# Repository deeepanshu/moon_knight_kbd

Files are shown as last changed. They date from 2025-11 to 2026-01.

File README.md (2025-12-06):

# Moon Knight Keyboard

A custom split keyboard project with multiple hardware iterations and utilities.

## Project Structure

- **moon_knight_v1/** - Initial keyboard design
- **moon_knight_v2_left/** & **moon_knight_v2_right/** - Second iteration split keyboard
- **moon_knight_v3/** - Third iteration
- **moon_knight_v4/** - Latest iteration
- **firmwares/** - Keyboard firmware configurations
- **keeb_utils/** - Utility tools for the keyboard
  - **layer-display/** - Real-time layer visualization utility

## Resources

- [Switch Placement Grid Guide](https://discord.com/channels/1025609366180728904/1096999853084655717/1358123429684838441) - Discord discussion on proper switch placement in grid layout

## Hardware Files

- `moon_knight_v2_case_design.stl` - Case design for v2
- `moon_knight_v2_switch_plates.stl` - Switch plates for v2

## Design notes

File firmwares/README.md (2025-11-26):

I am creating this folder to keep track of firmwares I used in QMK.
This folders contents should be symlinks in qmk_firmware/keyboards folder.

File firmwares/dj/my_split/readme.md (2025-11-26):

# dj/my_split

dj/my_split

*A short description of the keyboard/project*

* Keyboard Maintainer: [Deepanshu Jain](https://github.com/deeepanshu)
* Hardware Supported: *The PCBs, controllers supported*
* Hardware Availability: *Links to where you can find this hardware*

Make example for this keyboard (after setting up your build environment):

    make dj/my_split:default

Flashing example for this keyboard:

    make dj/my_split:default:flash

See the [build environment setup](https://docs.qmk.fm/#/getting_started_build_tools) and the [make instructions](https://docs.qmk.fm/#/getting_started_make_guide) for more information. Brand new to QMK? Start with our [Complete Newbs Guide](https://docs.qmk.fm/#/newbs).

## Bootloader

Enter the bootloader in 3 ways:

* **Bootmagic reset**: Hold down the key at (0,0) in the matrix (usually the top left key or Escape) and plug in the keyboard
* **Physical reset button**: Briefly press the button on the back of the PCB - some may have pads you must short instead
* **Keycode in layout**: Press the key mapped to `QK_BOOT` if it is available

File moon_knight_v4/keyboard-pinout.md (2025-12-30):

## Moon Knight V4 Keyboard Pinout (Per Side)

### Matrix (4 rows × 6 columns)
**Rows:**
- Row 0: GPIO 4
- Row 1: GPIO 5
- Row 2: GPIO 6
- Row 3: GPIO 7

**Columns:**
- Col 0: GPIO 8
- Col 1: GPIO 9
- Col 2: GPIO 20
- Col 3: GPIO 21
- Col 4: GPIO 22
- Col 5: GPIO 23

### LEDs (27 addressable per side)
- LED Data: GPIO 25 (5V RGB output)

### TRRS Split Communication
- TX: GPIO 0 (UART transmit)
- RX: GPIO 1 (UART receive)

### OLED Display
- SDA: GPIO 2 (I2C data)
- SCL: GPIO 3 (I2C clock)

### Pin Summary
Total pins used: 15
- Matrix: 10 pins (4 rows + 6 cols)
- RGB LEDs: 1 pin
- TRRS: 2 pins
- OLED: 2 pins

### Unusable Pins
- **D+, D-** - USB data (required)
- **RAW, GND, 3V3, nRST** - Power/reset lines
- **GPIO 12-16** - Bottom pads (avoiding per requirements)

### Available GPIO Pins
Total available: 18 pins (0-11, 20-23, 26-29)
Used: 15 pins
Remaining: GPIO 10, 11, 26 (3 pins free for expansion)

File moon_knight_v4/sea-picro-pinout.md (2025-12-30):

## Sea-Picro EXT Pinout

### Left Side
- **D+** - USB Data Positive
- **0** - TX (UART)
- **1** - RX (UART)
- **GND** - Ground
- **GND** - Ground
- **2** - SDA (I2C)
- **3** - SCL (I2C)
- **4** - GPIO
- **5** - GPIO
- **6** - GPIO
- **7** - GPIO
- **8** - GPIO
- **9** - GPIO

### Right Side
- **D-** - USB Data Negative
- **RAW** - Raw power input
- **GND** - Ground
- **nRST** - Reset (active low)
- **3V3** - 3.3V output
- **29** - ADC3
- **28** - ADC2
- **27** - ADC1
- **26** - ADC0
- **22** - SCK (SPI)
- **20** - MISO (SPI)
- **23** - MOSI (SPI)
- **21** - nCS (SPI)

### Bottom Pads
- **12, 13, 14, 15, 16** - Extended GPIO
- **25** - 5V RGB output

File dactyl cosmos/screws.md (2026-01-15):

# Dactly Cosmos

### Screws and Heat inserts notes

You'll need 14 M3 x 6mm screws with countersunk heads and 14 screw inserts to fasten the base plate to the case. Check the Screws Documentation to make sure you have the correctly sized parts.
https://ryanis.cool/cosmos/docs/screws/

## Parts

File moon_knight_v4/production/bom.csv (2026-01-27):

Designator | Footprint | Quantity | Value | LCSC Part #
C1, C10, C11, C12, C13, C14, C15, C16, C17, C18, C19, C2, C20, C21, C3, C4, C5, C6, C7, C8, C9 | 1206 | 21 | 0.1µF
CH1, CH10, CH11, CH12, CH13, CH14, CH15, CH16, CH17, CH18, CH19, CH2, CH20, CH3, CH4, CH5, CH6, CH7, CH8, CH9 | SW_choc_v1_HS_CPG135001S30_1u | 20 | choc_v1_SW_HS
CH21 | SW_choc_v1_HS_CPG135001S30_1.5u | 1 | choc_v1_SW_HS
D1, D10, D11, D12, D13, D14, D15, D16, D17, D18, D19, D2, D20, D21, D3, D4, D5, D6, D7, D8, D9 | D_SOD-123 | 21 | 1N4148W
J1 | CON_MJ-4PP-9 | 1 | AudioJack4
LED1, LED10, LED11, LED12, LED13, LED14, LED15, LED16, LED17, LED18, LED19, LED2, LED20, LED21, LED3, LED4, LED5, LED6, LED7, LED8, LED9 | LED_6028R | 21 | SK6812MINI-E
R1, R2 | 1206 | 2 | R
R3 | 1206 | 1 | 47R

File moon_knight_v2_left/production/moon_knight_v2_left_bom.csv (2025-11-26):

Designator | Footprint | Quantity | Value | LCSC Part #
C1, C10, C11, C12, C13, C14, C15, C16, C17, C18, C19, C2, C20, C21, C22, C3, C4, C5, C6, C7, C8, C9 | 1206 | 22 | 0.1µF
C23, C24, C25 | 1210 | 3 | 100uF
CH1, CH10, CH11, CH12, CH13, CH14, CH15, CH16, CH17, CH18, CH19, CH2, CH20, CH3, CH4, CH5, CH6, CH7, CH8, CH9 | SW_choc_v1_HS_CPG135001S30_1u | 20 | choc_v1_SW_HS
CH21, CH22 | SW_choc_v1_HS_CPG135001S30_1.5u | 2 | choc_v1_SW_HS
D1, D10, D11, D12, D13, D14, D15, D16, D17, D18, D19, D2, D20, D21, D22, D3, D4, D5, D6, D7, D8, D9 | D_SOD-123 | 22 | 1N4148W
J1 | CON_MJ-4PP-9_Reversible | 1 | AudioJack4
LED1, LED10, LED11, LED12, LED13, LED14, LED15, LED16, LED17, LED18, LED19, LED2, LED20, LED21, LED22, LED3, LED4, LED5, LED6, LED7, LED8, LED9 | LED_6028R | 22 | SK6812MINI-E
R1, R2 | 1206 | 2 | R
R3 | 1206 | 1 | 47R

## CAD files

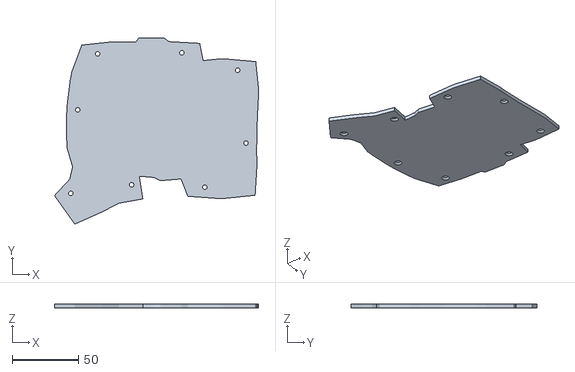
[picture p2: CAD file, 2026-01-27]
cosmotyl-6x4/cosmotyl-6x4-plateright.stl
154.1 x 140.6 x 3.00

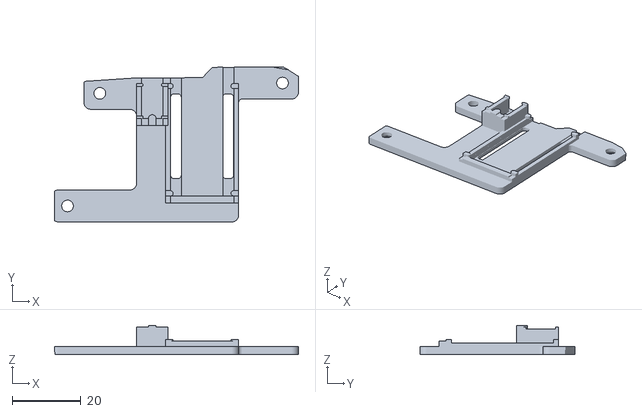
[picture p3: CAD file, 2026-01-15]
dactyl cosmos/cosmotyl-holderright.stl
71.0 x 45.1 x 8.50

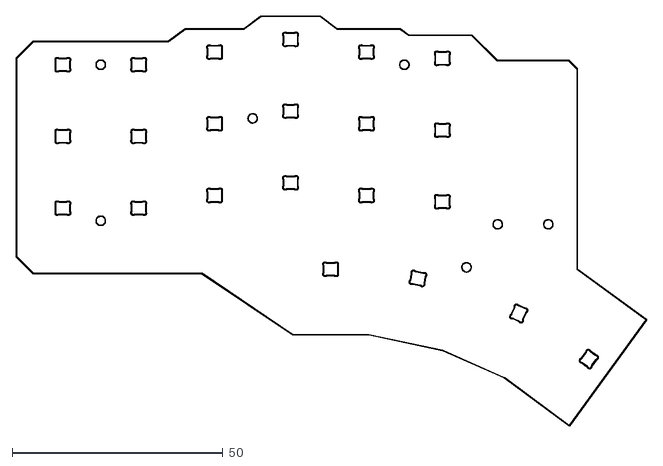
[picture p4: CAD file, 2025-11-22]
moon_knight_v2_left/dxfs/moon_knight_v2_left-Edge_Cuts.dxf
149.5 x 97.1

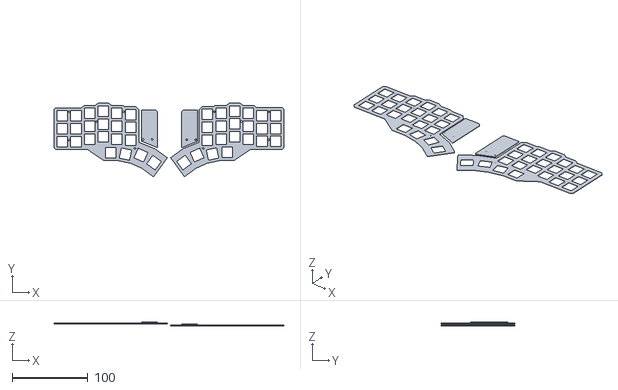
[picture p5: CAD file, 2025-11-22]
moon_knight_v2_switch_plates.stl
303.0 x 97.2 x 5.00

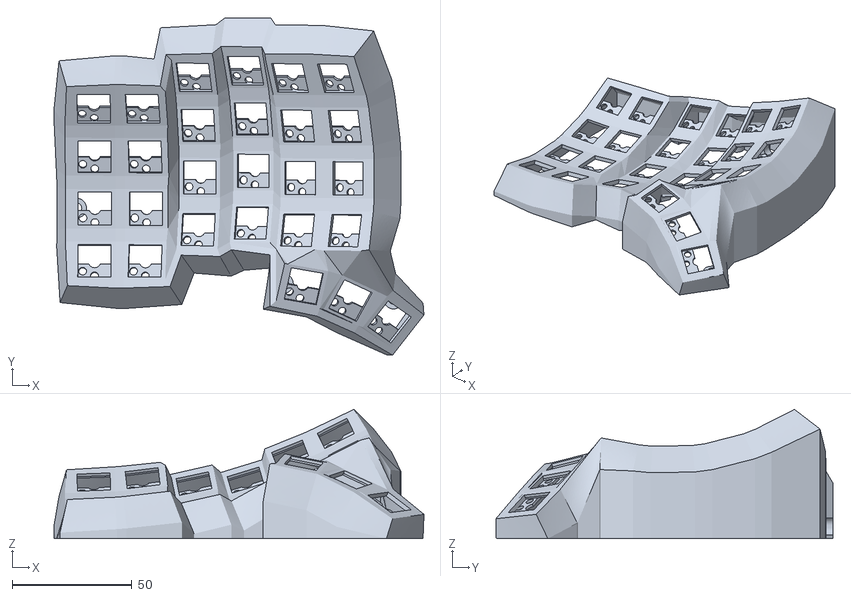
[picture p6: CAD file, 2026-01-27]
cosmotyl-6x4/cosmotyl-6x4-caseleft.stl
154.5 x 140.8 x 53.9

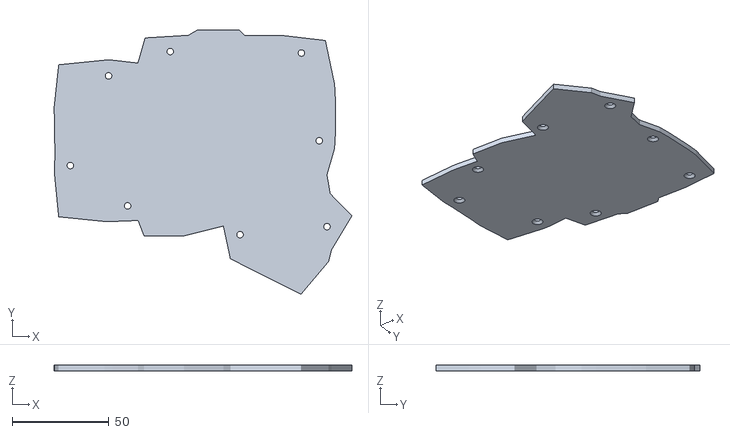
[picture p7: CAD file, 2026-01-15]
dactyl cosmos/cosmotyl-plateleft.stl
154.3 x 136.9 x 3.00

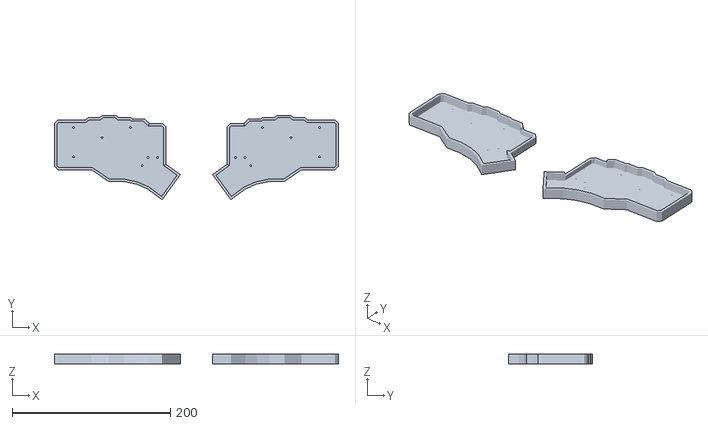
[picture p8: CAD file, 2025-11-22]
moon_knight_v2_case_design.stl
358.6 x 106.6 x 12.0

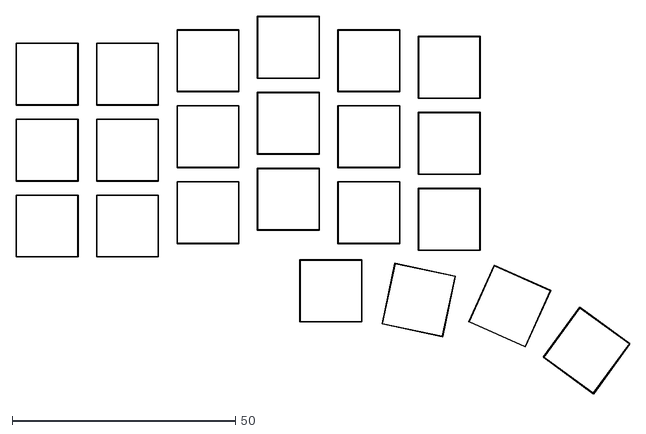
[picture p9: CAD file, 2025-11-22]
moon_knight_v2_left/dxfs/moon_knight_v2_left-F_Courtyard.dxf
137.3 x 84.4

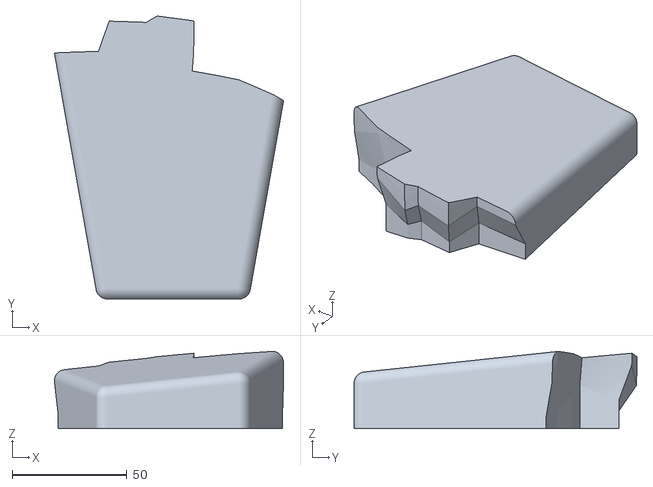
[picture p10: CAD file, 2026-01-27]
cosmotyl-6x4/cosmotyl-6x4-wristrestleft.stl
100.0 x 123.4 x 33.7

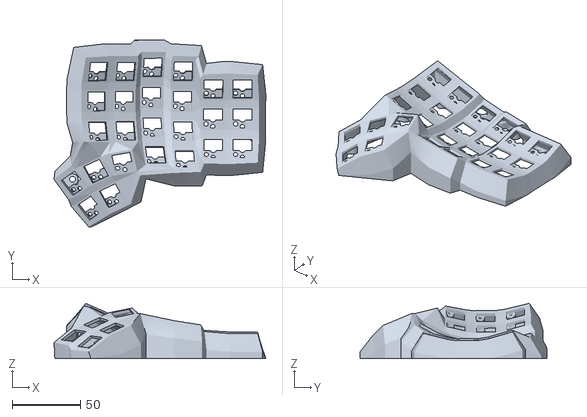
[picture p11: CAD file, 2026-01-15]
dactyl cosmos/cosmotyl-caseright.stl
154.9 x 136.9 x 40.4

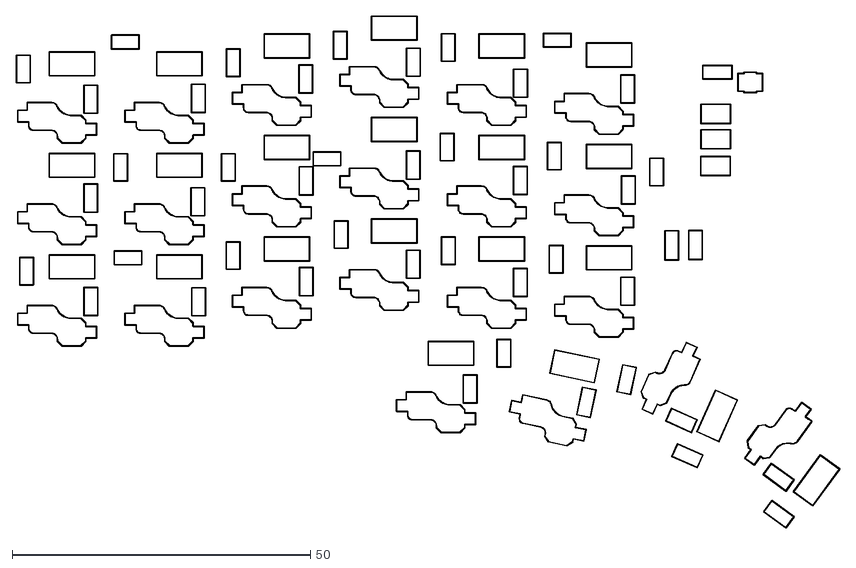
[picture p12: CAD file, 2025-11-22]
moon_knight_v2_left/dxfs/moon_knight_v2_left-B_Courtyard.dxf
137.9 x 85.8

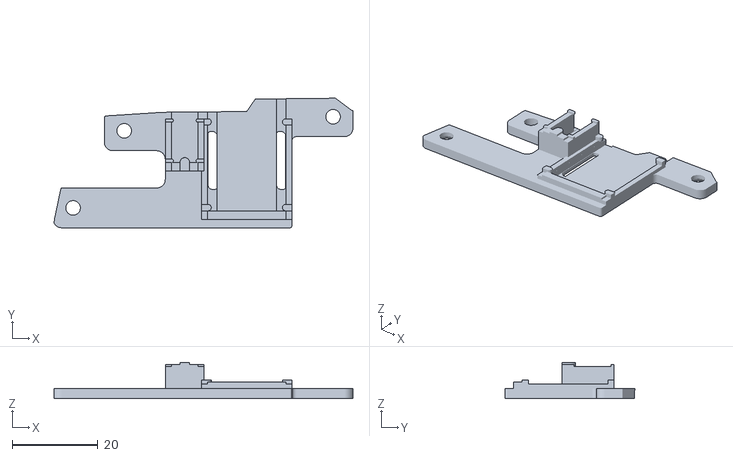
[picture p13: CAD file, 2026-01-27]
cosmotyl-6x4/cosmotyl-6x4-holderright.stl
69.8 x 30.3 x 8.50

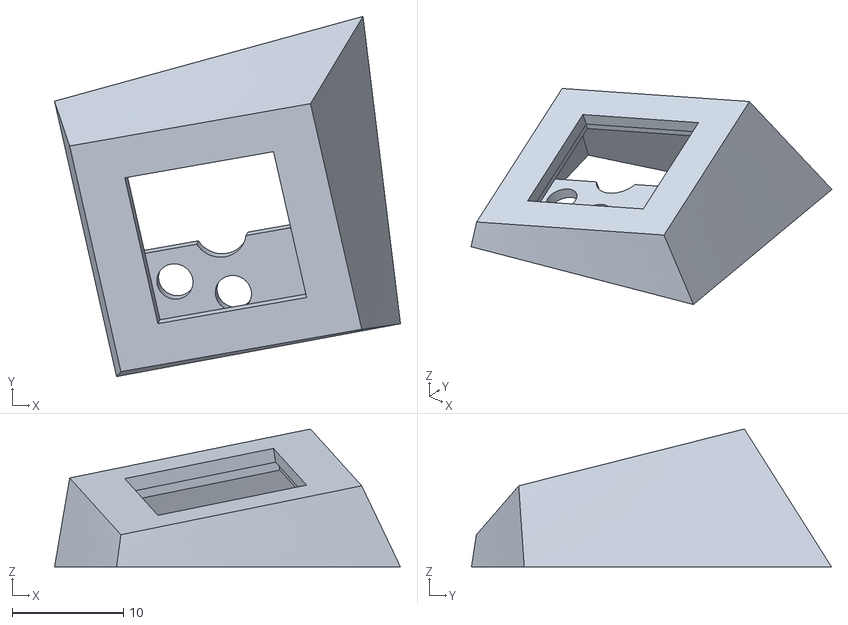
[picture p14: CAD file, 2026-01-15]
dactyl cosmos/cosmotyl-casetest.stl
31.1 x 32.4 x 12.4

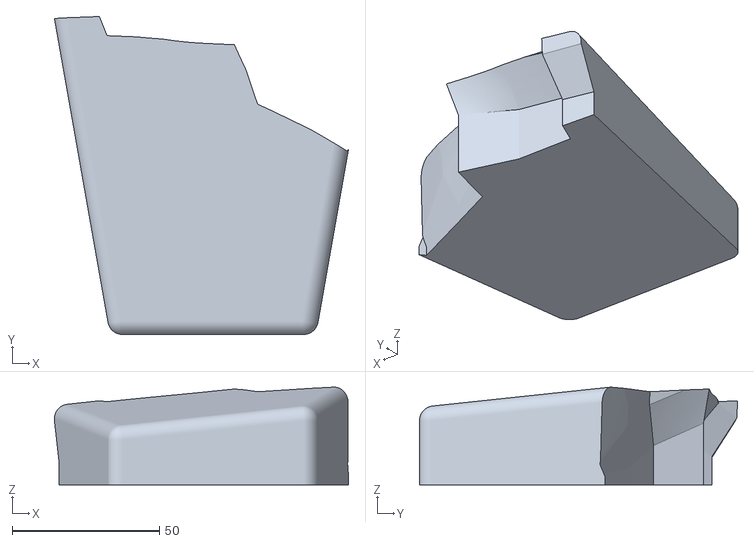
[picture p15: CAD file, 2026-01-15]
dactyl cosmos/cosmotyl-wristrestleft.stl
99.9 x 108.0 x 33.2

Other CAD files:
cosmotyl-6x4/cosmotyl-6x4-caseright.stl
dactyl cosmos/cosmotyl-caseleft.stl
cosmotyl-6x4/cosmotyl-6x4-casetest.stl
cosmotyl-6x4/cosmotyl-6x4-plateleft.stl
cosmotyl-6x4/cosmotyl-6x4-holderleft.stl
cosmotyl-6x4/cosmotyl-6x4-wristrestright.stl
dactyl cosmos/cosmotyl-holderleft.stl
dactyl cosmos/cosmotyl-plateright.stl
dactyl cosmos/cosmotyl-wristrestright.stl
moon_knight_v1_right/dxfs/moon_knight_v1_right-B_Courtyard.dxf
moon_knight_v1_right/dxfs/moon_knight_v1_right-B_Silkscreen.dxf
moon_knight_v1_right/dxfs/moon_knight_v1_right-Edge_Cuts.dxf
moon_knight_v1_right/dxfs/moon_knight_v1_right-F_Silkscreen.dxf
moon_knight_v1_right/dxfs/moon_knight_v1_right-User_Drawings.dxf
moon_knight_v1_right/moon_knight_v1_right.step
moon_knight_v2_right/dxfs/moon_knight_v2_right-B_Courtyard.dxf
moon_knight_v2_right/dxfs/moon_knight_v2_right-B_Silkscreen.dxf
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

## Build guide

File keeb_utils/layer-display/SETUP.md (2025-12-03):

# Layer Display Setup

## Running at Login (Recommended)

### Option 1: macOS Login Items (Simplest)

1. **Open the script in Automator:**
   - Open **Automator** (search in Spotlight)
   - Create new **Application**
   - Add action: "Run Shell Script"
   - Paste this:
     ```bash
     /Users/djain/Desktop/moon_knight_kbd/keeb_utils/layer-display/launch-layer-display.sh
     ```
   - Save as: `LayerDisplay.app` (save to Desktop or Applications)

2. **Add to Login Items:**
   - Open **System Settings** → **General** → **Login Items**
   - Click **+** under "Open at Login"
   - Select `LayerDisplay.app`
   - Done! It will start automatically on login

### Option 2: launchd (More Robust)

Create a LaunchAgent that survives crashes and runs in background:

```bash
# Create LaunchAgent directory if it doesn't exist
mkdir -p ~/Library/LaunchAgents

# Create plist file (already provided below)
# Then load it:
launchctl load ~/Library/LaunchAgents/com.user.layer-display.plist

# To unload:
launchctl unload ~/Library/LaunchAgents/com.user.layer-display.plist
```

**Note:** I can generate the plist file if you want this option.

### Option 3: Build .app Bundle (Best UX, Most Complex)

Requires installing py2app and building a proper macOS application.

## Manual Launch

Just double-click `launch-layer-display.sh` (or run from terminal)

## Current Status

- ✅ Menubar app displays "Layer 0"
- ✅ Shows dropdown menu with Hello World and layer list
- ⏳ HID communication not yet wired up
- ⏳ Firmware doesn't send layer data yet

## Next Steps

1. Extract VID/PID from keyboard firmware
2. Add Raw HID to QMK firmware
3. Wire up HID listener to update menubar text

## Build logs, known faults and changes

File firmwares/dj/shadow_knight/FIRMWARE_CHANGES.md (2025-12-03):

# Adding Raw HID Layer Reporting to QMK Firmware

## Overview

This guide shows how to make your keyboard send layer change notifications to the macOS menubar app via Raw HID.

## Changes Needed

### 1. Enable Raw HID in `rules.mk`

Add this line to `/firmwares/dj/moon_knight/keymaps/vial/rules.mk`:

```make
RAW_ENABLE = yes
```

### 2. Add Layer Reporting Code to `keymap.c`

Add this code to `/firmwares/dj/moon_knight/keymaps/vial/keymap.c`:

```c
#ifdef RAW_ENABLE
#include "raw_hid.h"

// Message IDs for HID communication
#define MSG_LAYER_UPDATE 0x01

// Track current layer to only send updates on changes
static uint8_t current_layer = 0;

// Called by QMK whenever the layer changes
layer_state_t layer_state_set_user(layer_state_t state) {
    uint8_t new_layer = get_highest_layer(state);

    // Only send if layer actually changed
    if (new_layer != current_layer) {
        current_layer = new_layer;

        // Send HID message: [MSG_ID, LAYER, 0, 0, ..., 0] (32 bytes total)
        uint8_t data[32] = {0};
        data[0] = MSG_LAYER_UPDATE;
        data[1] = current_layer;

        raw_hid_send(data, sizeof(data));
    }

    return state;
}
#endif
```

### 3. Where to Add the Code

Insert the Raw HID code **after line 88** (after the keymaps definition, before or after `keyboard_post_init_user()`).

Your `keymap.c` structure will be:
```
Line 1-88:   Existing keymaps
Line 89+:    Raw HID code (new)
Line 90+:    keyboard_post_init_user() (existing)
```

## Complete Example

Here's what the end of your `keymap.c` should look like:

```c
    [3] = LAYOUT_split_3x6_4(
        KC_F1,   KC_F2,   KC_F3,   KC_F4,   KC_F5,   KC_F6,                              KC_F7,   KC_F8,   KC_F9,   KC_F10,  KC_F11,  KC_F12,
        _______, _______, _______, _______, _______, _______,                            KC_MPRV, KC_VOLD, KC_VOLU, KC_MNXT, KC_MUTE, KC_MPLY,
        _______, _______, _______, _______, _______, _______,                            _______, _______, _______, _______, _______, _______,
                                            _______, _______, _______, _______,          _______, _______, _______, _______
    )
};

#ifdef RAW_ENABLE
#include "raw_hid.h"

#define MSG_LAYER_UPDATE 0x01

static uint8_t current_layer = 0;

layer_state_t layer_state_set_user(layer_state_t state) {
    uint8_t new_layer = get_highest_layer(state);

    if (new_layer != current_layer) {
        current_layer = new_layer;

        uint8_t data[32] = {0};
        data[0] = MSG_LAYER_UPDATE;
        data[1] = current_layer;

        raw_hid_send(data, sizeof(data));
    }

    return state;
}
#endif

void keyboard_post_init_kb(void) {
    keyboard_post_init_user();
}

void keyboard_post_init_user(void) {
    // debug_enable=true;
    // debug_matrix=true;
    // debug_keyboard=true;

    rgblight_enable_noeeprom();
    rgblight_mode_noeeprom(RGBLIGHT_MODE_RAINBOW_MOOD + 1);
}
```

## Building and Flashing

After making these changes:

```bash
# Navigate to your QMK firmware directory (where the symlink points)
cd ~/qmk_firmware

# Build the firmware
qmk compile -kb dj/moon_knight -km vial

# Flash to keyboard (hold bootmagic keys and plug in)
qmk flash -kb dj/moon_knight -km vial
```

## Testing

1. Flash the updated firmware
2. Run the menubar app: `./launch-layer-display.sh`
3. Press your layer keys (MO(1), MO(2), MO(3))
4. Watch the menubar text change in real-time!

## How It Works

- **QMK Side:** `layer_state_set_user()` is called whenever layers change
- **Sends:** 32-byte HID packet with [MSG_ID, LAYER_NUMBER, ...]
- **Python Side:** HID listener receives packet and updates menubar text
- **Protocol:** Raw HID (no drivers needed, works out of the box on macOS)

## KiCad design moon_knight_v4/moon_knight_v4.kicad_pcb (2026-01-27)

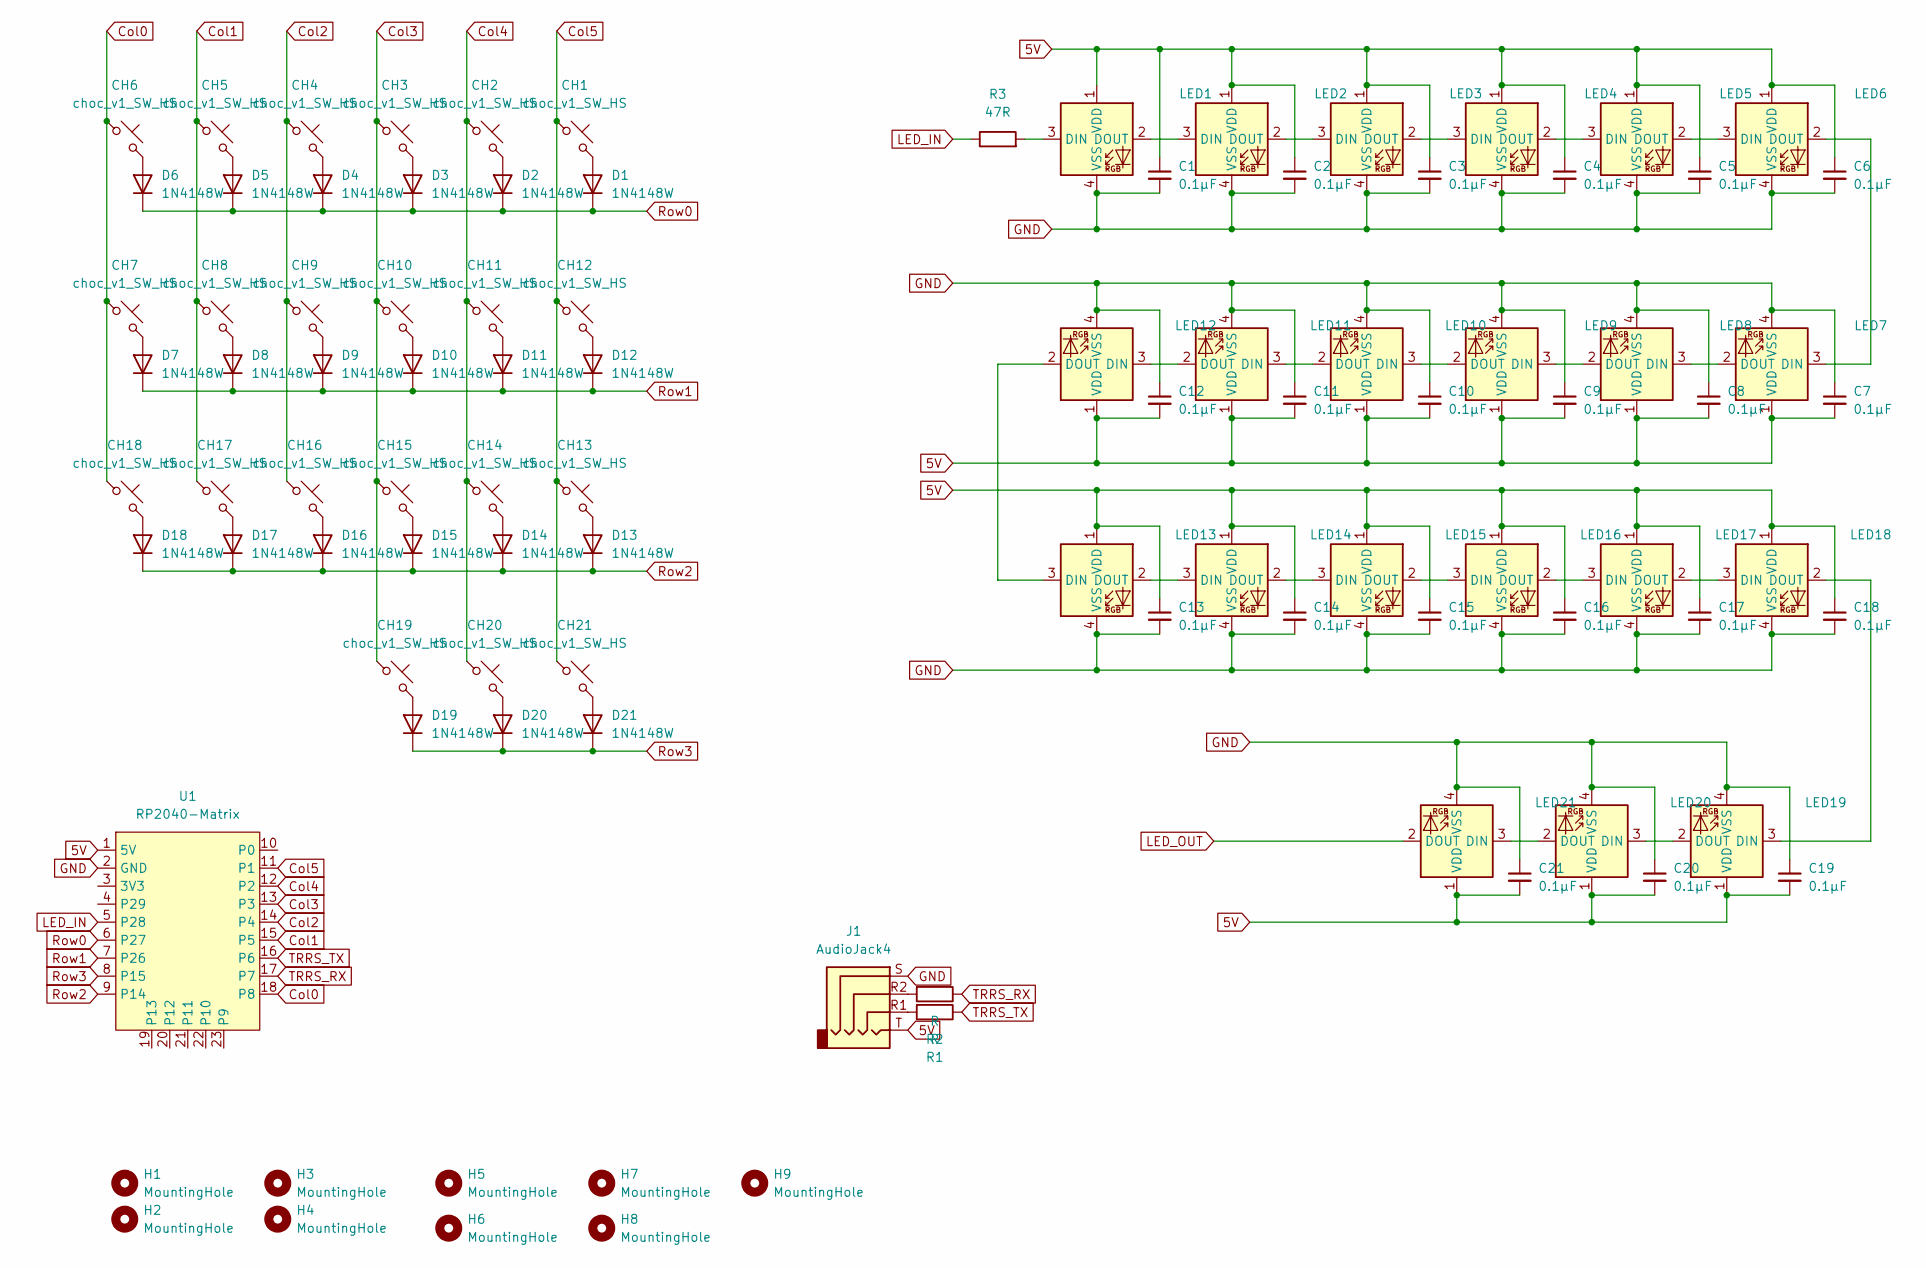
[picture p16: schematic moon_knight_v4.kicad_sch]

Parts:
C1, C2, C3, C4, C5, C6, C7, C8, C9, C10, C11, C12, C13, C14, C15, C16, C17, C18, C19, C20, C21: 0.1µF; C_1206_3216Metric
CH1, CH2, CH3, CH4, CH5, CH6, CH7, CH8, CH9, CH10, CH11, CH12, CH13, CH14, CH15, CH16, CH17, CH18, CH19, CH20: choc_v1_SW_HS; SW_choc_v1_HS_CPG135001S30_1u
CH21: choc_v1_SW_HS; SW_choc_v1_HS_CPG135001S30_1.5u
D1, D2, D3, D4, D5, D6, D7, D8, D9, D10, D11, D12, D13, D14, D15, D16, D17, D18, D19, D20, D21: 1N4148W; D_SOD-123
H1, H2, H3, H4, H5, H6, H7, H8, H9: MountingHole; MountingHole_2.2mm_M2
J1: AudioJack4; CON_MJ-4PP-9
LED1, LED2, LED3, LED4, LED5, LED6, LED7, LED8, LED9, LED10, LED11, LED12, LED13, LED14, LED15, LED16, LED17, LED18, LED19, LED20, LED21: SK6812MINI-E; LED_6028R
R1, R2: R; R_1206_3216Metric_Pad1.30x1.75mm_HandSolder
R3: 47R; R_1206_3216Metric_Pad1.30x1.75mm_HandSolder
U1: RP2040-Matrix; RP2040-Matrix_AH

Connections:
5V: C1.1, C2.1, C3.1, C4.1, C5.1, C6.1, C7.2, C8.2, C9.2, C10.2, C11.2, C12.2, C13.1, C14.1, C15.1, C16.1, C17.1, C18.1, C19.2, C20.2, C21.2, J1.T, LED1.1 (VDD), LED2.1 (VDD), LED3.1 (VDD), LED4.1 (VDD), LED5.1 (VDD), LED6.1 (VDD), LED7.1 (VDD), LED8.1 (VDD), LED9.1 (VDD), LED10.1 (VDD), LED11.1 (VDD), LED12.1 (VDD), LED13.1 (VDD), LED14.1 (VDD), LED15.1 (VDD), LED16.1 (VDD), LED17.1 (VDD), LED18.1 (VDD), LED19.1 (VDD), LED20.1 (VDD), LED21.1 (VDD), U1.1 (5V)
Col0: CH6.1, CH7.1, CH18.1, U1.18 (P8)
Col1: CH5.1, CH8.1, CH17.1, U1.15 (P5)
Col2: CH4.1, CH9.1, CH16.1, U1.14 (P4)
Col3: CH3.1, CH10.1, CH15.1, CH19.1, U1.13 (P3)
Col4: CH2.1, CH11.1, CH14.1, CH20.1, U1.12 (P2)
Col5: CH1.1, CH12.1, CH13.1, CH21.1, U1.11 (P1)
GND: C1.2, C2.2, C3.2, C4.2, C5.2, C6.2, C7.1, C8.1, C9.1, C10.1, C11.1, C12.1, C13.2, C14.2, C15.2, C16.2, C17.2, C18.2, C19.1, C20.1, C21.1, J1.S, LED1.4 (VSS), LED2.4 (VSS), LED3.4 (VSS), LED4.4 (VSS), LED5.4 (VSS), LED6.4 (VSS), LED7.4 (VSS), LED8.4 (VSS), LED9.4 (VSS), LED10.4 (VSS), LED11.4 (VSS), LED12.4 (VSS), LED13.4 (VSS), LED14.4 (VSS), LED15.4 (VSS), LED16.4 (VSS), LED17.4 (VSS), LED18.4 (VSS), LED19.4 (VSS), LED20.4 (VSS), LED21.4 (VSS), U1.2 (GND)
LED_IN: R3.1, U1.5 (P28)
LED_OUT: LED21.2 (DOUT)
unnamed: CH1.2, D1.2 (A)
unnamed: CH2.2, D2.2 (A)
unnamed: CH3.2, D3.2 (A)
unnamed: CH4.2, D4.2 (A)
unnamed: CH5.2, D5.2 (A)
unnamed: CH6.2, D6.2 (A)
unnamed: CH7.2, D7.2 (A)
unnamed: CH8.2, D8.2 (A)
unnamed: CH9.2, D9.2 (A)
unnamed: CH10.2, D10.2 (A)
unnamed: CH11.2, D11.2 (A)
unnamed: CH12.2, D12.2 (A)
unnamed: CH13.2, D13.2 (A)
unnamed: CH14.2, D14.2 (A)
unnamed: CH15.2, D15.2 (A)
unnamed: CH16.2, D16.2 (A)
unnamed: CH17.2, D17.2 (A)
unnamed: CH18.2, D18.2 (A)
unnamed: CH19.2, D19.2 (A)
unnamed: CH20.2, D20.2 (A)
unnamed: CH21.2, D21.2 (A)
unnamed: J1.R1, R1.2
unnamed: J1.R2, R2.2
unnamed: LED1.3 (DIN), R3.2
unnamed: LED1.2 (DOUT), LED2.3 (DIN)
unnamed: LED2.2 (DOUT), LED3.3 (DIN)
unnamed: LED3.2 (DOUT), LED4.3 (DIN)
unnamed: LED4.2 (DOUT), LED5.3 (DIN)
unnamed: LED5.2 (DOUT), LED6.3 (DIN)
unnamed: LED6.2 (DOUT), LED7.3 (DIN)
unnamed: LED7.2 (DOUT), LED8.3 (DIN)
unnamed: LED8.2 (DOUT), LED9.3 (DIN)
unnamed: LED9.2 (DOUT), LED10.3 (DIN)
unnamed: LED10.2 (DOUT), LED11.3 (DIN)
unnamed: LED11.2 (DOUT), LED12.3 (DIN)
unnamed: LED12.2 (DOUT), LED13.3 (DIN)
unnamed: LED13.2 (DOUT), LED14.3 (DIN)
unnamed: LED14.2 (DOUT), LED15.3 (DIN)
unnamed: LED15.2 (DOUT), LED16.3 (DIN)
unnamed: LED16.2 (DOUT), LED17.3 (DIN)
unnamed: LED17.2 (DOUT), LED18.3 (DIN)
unnamed: LED18.2 (DOUT), LED19.3 (DIN)
unnamed: LED19.2 (DOUT), LED20.3 (DIN)
unnamed: LED20.2 (DOUT), LED21.3 (DIN)
Row0: D1.1 (K), D2.1 (K), D3.1 (K), D4.1 (K), D5.1 (K), D6.1 (K), U1.6 (P27)
Row1: D7.1 (K), D8.1 (K), D9.1 (K), D10.1 (K), D11.1 (K), D12.1 (K), U1.7 (P26)
Row2: D13.1 (K), D14.1 (K), D15.1 (K), D16.1 (K), D17.1 (K), D18.1 (K), U1.9 (P14)
Row3: D19.1 (K), D20.1 (K), D21.1 (K), U1.8 (P15)
TRRS_RX: R2.1, U1.17 (P7)
TRRS_TX: R1.1, U1.16 (P6)

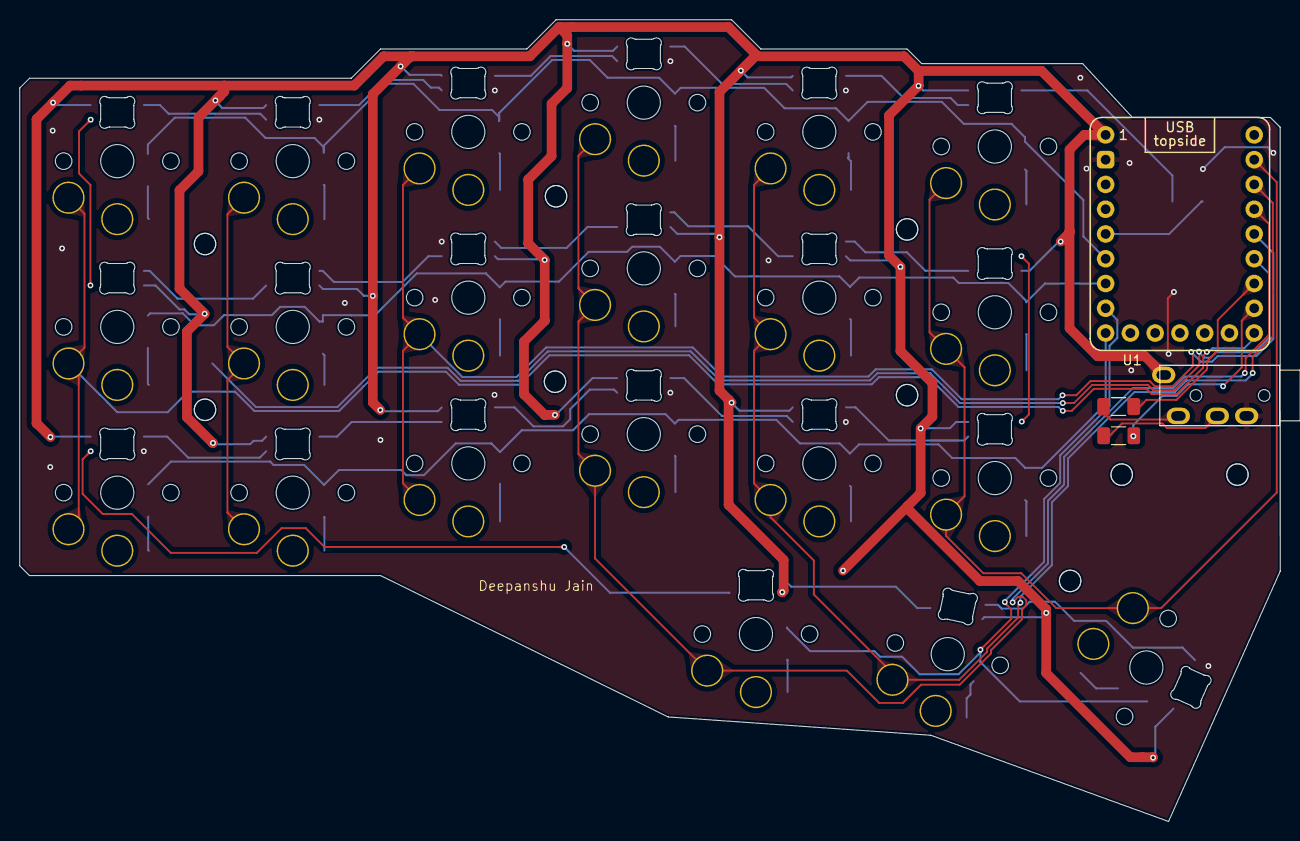
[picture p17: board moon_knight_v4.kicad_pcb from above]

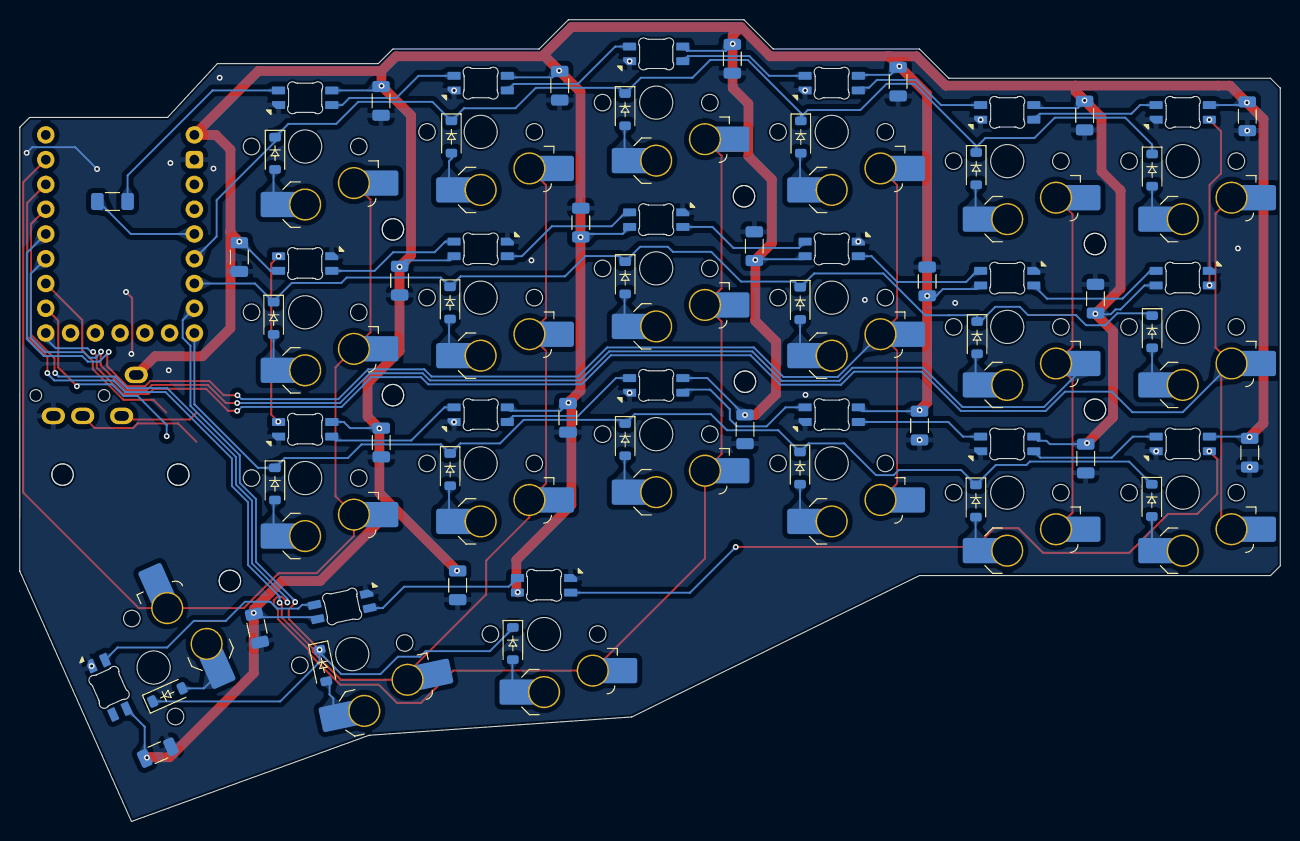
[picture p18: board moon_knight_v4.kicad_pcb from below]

Board: 2 copper layers, 129.3 x 82.2 mm, 98 parts (85 on the bottom side), 59 nets.

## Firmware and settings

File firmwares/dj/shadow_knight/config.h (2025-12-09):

#pragma once

#define MASTER_LEFT

#define SERIAL_DEBUG
#define SPLIT_USB_DETECT
#define SPLIT_USB_TIMEOUT 1000

#define SERIAL_USART_FULL_DUPLEX
#define SERIAL_USART_PIN_SWAP
#define SERIAL_USART_TX_PIN GP6
#define SERIAL_USART_RX_PIN GP7
#define WS2812_DI_PIN_RIGHT GP28

#define RP2040_BOOTLOADER_DOUBLE_TAP_RESET
#define RP2040_BOOTLOADER_DOUBLE_TAP_RESET_TIMEOUT 500U
#define RP2040_BOOTLOADER_DOUBLE_TAP_RESET_LED GP16

#ifndef CHORDAL_HOLD
#define CHORDAL_HOLD
#endif

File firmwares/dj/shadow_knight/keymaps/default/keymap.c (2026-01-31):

// Copyright 2023 QMK
// SPDX-License-Identifier: GPL-2.0-or-later

#include QMK_KEYBOARD_H

const uint16_t PROGMEM keymaps[][MATRIX_ROWS][MATRIX_COLS] = {
     /*
      * LAYER 0 - BASE (Default typing layer)
      * Home Row Mods: F and J act as Shift when held
      * ┌───┬───┬───┬───┬───┬───┐       ┌───┬───┬───┬───┬───┬───┐
      * │Esc│ Q │ W │ E │ R │ T │       │ Y │ U │ I │ O │ P │Bsp│
      * ├───┼───┼───┼───┼───┼───┤       ├───┼───┼───┼───┼───┼───┤
      * │Ctl│ A │ S │ D │F/Sft│ G │     │ H │J/Sft│ K │ L │ ; │ ' │
      * ├───┼───┼───┼───┼───┼───┤       ├───┼───┼───┼───┼───┼───┤
      * │Sft│ Z │ X │ C │ V │ B │       │ N │ M │ , │ . │ / │Sft│
      * └───┴───┴───┴───┴───┴───┘       └───┴───┴───┴───┴───┴───┘
      *           ┌───┬───┬───┐       ┌───┬───┬───┐
      *           │Tab│GUI│Spc│       │L2 │Spc│Ent│
      *           └───┴───┴───┘       └───┴───┴───┘
      */
    [0] = LAYOUT_split_3x6_3(
        KC_ESC,  KC_Q,    KC_W,    KC_E,    KC_R,    KC_T,                               KC_Y,    KC_U,    KC_I,    KC_O,    KC_P,    KC_BSPC,
        KC_LCTL, KC_A,    KC_S,    KC_D,    LSFT_T(KC_F), KC_G,                          KC_H,    RSFT_T(KC_J), KC_K, KC_L,   KC_SCLN, KC_QUOT,
        KC_LSFT, KC_Z,    KC_X,    KC_C,    KC_V,    KC_B,                               KC_N,    KC_M,    KC_COMM, KC_DOT,  KC_SLSH, KC_RSFT,
                                            KC_TAB,  KC_LGUI, KC_SPC,                     MO(2),   KC_SPC,  KC_ENT
    ),

     /*
      * LAYER 1 - NUMBERS & NAVIGATION
      * ┌───┬───┬───┬───┬───┬───┐       ┌───┬───┬───┬───┬───┬───┐
      * │   │ 1 │ 2 │ 3 │ 4 │ 5 │       │ 6 │ 7 │ 8 │ 9 │ 0 │Del│
      * ├───┼───┼───┼───┼───┼───┤       ├───┼───┼───┼───┼───┼───┤
      * │   │   │   │   │   │   │       │ ← │ ↓ │ ↑ │ → │   │   │
      * ├───┼───┼───┼───┼───┼───┤       ├───┼───┼───┼───┼───┼───┤
      * │   │   │   │   │   │   │       │Hom│PgD│PgU│End│   │   │
      * └───┴───┴───┴───┴───┴───┘       └───┴───┴───┴───┴───┴───┘
      *           ┌───┬───┬───┐       ┌───┬───┬───┐
      *           │   │   │   │       │   │   │   │
      *           └───┴───┴───┘       └───┴───┴───┘
      */
    [1] = LAYOUT_split_3x6_3(
        _______, KC_1,    KC_2,    KC_3,    KC_4,    KC_5,                               KC_6,    KC_7,    KC_8,    KC_9,    KC_0,    KC_DEL,
        _______, _______, _______, _______, _______, _______,                            KC_LEFT, KC_DOWN, KC_UP,   KC_RGHT, _______, _______,
        _______, _______, _______, _______, _______, _______,                            KC_HOME, KC_PGDN, KC_PGUP, KC_END,  _______, _______,
                                            _______, _______, _______,                    _______, _______, _______
    ),

     /*
      * LAYER 2 - SYMBOLS & BRACKETS (Hold right MO(2))
      * Mirrored brackets: Left hand opens, right hand closes
      * ┌───┬───┬───┬───┬───┬───┐       ┌───┬───┬───┬───┬───┬───┐
      * │   │ ! │ @ │ # │ $ │ % │       │ ~ │ ^ │ & │ * │ + │   │
      * ├───┼───┼───┼───┼───┼───┤       ├───┼───┼───┼───┼───┼───┤
      * │   │ ( │ [ │ { │ < │ _ │       │ - │ > │ } │ ] │ ) │   │
      * ├───┼───┼───┼───┼───┼───┤       ├───┼───┼───┼───┼───┼───┤
      * │   │   │   │   │ | │ = │       │ \ │   │   │   │   │   │
      * └───┴───┴───┴───┴───┴───┘       └───┴───┴───┴───┴───┴───┘
      *           ┌───┬───┬───┐       ┌───┬───┬───┐
      *           │   │   │L3 │       │   │   │   │
      *           └───┴───┴───┘       └───┴───┴───┘
      */
    [2] = LAYOUT_split_3x6_3(
        _______, KC_EXLM, KC_AT,   KC_HASH, KC_DLR,  KC_PERC,                            KC_TILD, KC_CIRC, KC_AMPR, KC_ASTR, KC_PLUS, _______,
        _______, KC_LPRN, KC_LBRC, KC_LCBR, KC_LABK, KC_UNDS,                            KC_MINS, KC_RABK, KC_RCBR, KC_RBRC, KC_RPRN, _______,
        _______, _______, _______, _______, KC_PIPE, KC_EQL,                             KC_BSLS, _______, _______, _______, _______, _______,
                                            _______, _______, MO(3),                      _______, _______, _______
    ),

     /*
      * LAYER 3 - FUNCTION KEYS & MEDIA (Hold MO(2) then press MO(3))
      * ┌───┬───┬───┬───┬───┬───┐       ┌───┬───┬───┬───┬───┬───┐
      * │F1 │F2 │F3 │F4 │F5 │F6 │       │F7 │F8 │F9 │F10│F11│F12│
      * ├───┼───┼───┼───┼───┼───┤       ├───┼───┼───┼───┼───┼───┤
      * │   │   │   │   │   │   │       │Prv│Vl-│Vl+│Nxt│Mut│Ply│
      * ├───┼───┼───┼───┼───┼───┤       ├───┼───┼───┼───┼───┼───┤
      * │   │   │   │   │   │   │       │   │   │   │   │   │   │
      * └───┴───┴───┴───┴───┴───┘       └───┴───┴───┴───┴───┴───┘
      *           ┌───┬───┬───┐       ┌───┬───┬───┐
      *           │   │   │   │       │   │   │   │
      *           └───┴───┴───┘       └───┴───┴───┘
      */
    [3] = LAYOUT_split_3x6_3(
        KC_F1,   KC_F2,   KC_F3,   KC_F4,   KC_F5,   KC_F6,                              KC_F7,   KC_F8,   KC_F9,   KC_F10,  KC_F11,  KC_F12,
        _______, _______, _______, _______, _______, _______,                            KC_MPRV, KC_VOLD, KC_VOLU, KC_MNXT, KC_MUTE, KC_MPLY,
        _______, _______, _______, _______, _______, _______,                            _______, _______, _______, _______, _______, _______,
                                            _______, _______, _______,                    _______, _______, _______
    )
};

void keyboard_post_init_user(void) {
    debug_enable=true;
    debug_matrix=true;
    debug_keyboard=true;

    rgblight_enable_noeeprom();
    rgblight_mode_noeeprom(RGBLIGHT_MODE_RAINBOW_MOOD + 1);

    // Setup GP16 as output for layer indicator LED
    gpio_set_pin_output(GP16);
    gpio_write_pin_low(GP16);  // Start with LED off

    uprintf("Keyboard initialized!\n");
    uprintf("Is master: %d\n", is_keyboard_master());
    uprintf("Split enabled: %d\n", 1);
}

layer_state_t layer_state_set_user(layer_state_t state) {
    // LED behavior based on active layer
    switch (get_highest_layer(state)) {
        case 0:  // Base layer
            gpio_write_pin_low(GP16);  // MCU LED off
            break;
        case 1:  // Numbers layer
        case 2:  // Symbols layer
        case 3:  // Function layer
            gpio_write_pin_high(GP16);  // MCU LED on
            break;
    }
    return state;
}

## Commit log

2025-11-12 Add splits
    [bom.csv, designators.csv, gerber_left_final_bom.csv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]
2025-12-03 feat: add layer detection system with Raw HID
    - Add Raw HID layer reporting to QMK firmware
    - Send layer updates via USB HID when layer changes
    - Only transmit on actual layer transitions
    - Implement macOS menubar app for layer visualization
    - Display current layer with compact indicator (L0-L3)
    - Parse and show Vial keymaps for all layers
    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
2025-12-03 fix: use Vial fork and install ARM toolchain in CI
    - Switch from qmk/qmk_firmware to vial-kb/vial-qmk
    - Install gcc-arm-none-eabi for RP2040 compilation
    - Use make instead of qmk compile for Vial builds
    - Add workflow path to build triggers
2025-12-03 perf: use QMK Docker image for faster builds
    - Use qmkfm/qmk_cli:latest container with pre-installed toolchain
    - Remove ARM toolchain installation step (already in image)
    - Remove QMK CLI installation step (already in image)
    - Speeds up build by 2-3x
2025-12-07 feat: add per-layer RGB colors and additional layers
    - Add solid RGB color per layer (0-5)
    - Layer 0: White, Layer 1: Blue, Layer 2: Green
    - Layer 3: Purple, Layer 4: Orange, Layer 5: Cyan
    - Add layers 4 and 5 (reserved, no-op for now)
    - Fix column staggering in Vial layout
    - Adjust right thumb cluster position (-1u)
    - Increase DYNAMIC_KEYMAP_LAYER_COUNT to 6
    [config.h, keymap.c]
2025-12-07 feat: update layer colors to custom palette
    - Layer 0: Dark blue-green (#264653)
    - Layer 1: Teal (#2a9d8f)
    - Layer 2: Sage green (#8ab17d)
    - Layer 3: Yellow (#e9c46a)
    - Layer 4: Orange (#f4a261)
    - Layer 5: Coral/red (#e76f51)
    - Add 1u vertical spacing for thumb cluster
    [keymap.c]
2025-12-07 refactor: add color constants and enable Vial RGB controls
    - Add RGB color constants at top of file for maintainability
    - Use constants throughout layer color switching code
    - Enable RGB lighting in Vial UI (qmk_rgblight)
2025-12-07 refactor: use QMK predefined HSV color constants
    - Remove custom color definitions to avoid conflicts
    - Use QMK's built-in HSV_* constants (HSV_CYAN, HSV_TEAL, etc.)
    - Cleaner code using standard QMK color palette
    [keymap.c]
2025-12-09 fix: add include guard for CHORDAL_HOLD to prevent redefinition error
    Wrapped CHORDAL_HOLD define with #ifndef guard to avoid compilation error
    when the macro is already defined via command line flags.
    [config.h]
2025-12-19 refactor: replace layer-specific solid colors with rainbow swirl effect
    - Remove layer-specific color switching in layer_state_set_user
    - Change RGB mode from static light to rainbow swirl animation
    - Keep HID layer notifications for external tools
    [keymap.c]
2025-12-30 V4 keyboard
    [bom.csv, designators.csv, moon_knight_v4.kicad_pcb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]
2026-01-15 v4 keeb
    [bom.csv, cosmotyl-caseleft.stl, cosmotyl-caseright.stl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]
2026-01-15 some commits
    [moon_knight_v3.kicad_pcb, moon_knight_v3.kicad_sch]
2026-02-01 Update shadow_knight Vial keymaps from .vil file (broken - thumb keys col 2,3,4)
    - Updated keymap.c with 4 layers from vial_moon_knight.vil
    - Layer 0: Base QWERTY with LT(3,BSPC), home row mods
    - Layer 1: Numbers & Navigation
    - Layer 2: Function keys & Media
    - Layer 3: Mouse keys
    - Updated config.h: DYNAMIC_KEYMAP_LAYER_COUNT = 4
    - keyboard.json: Left thumb mapped to columns 2,3,4
    - vial.json: Left thumb mapped to columns 2,3,4
    - BROKEN: Keys trigger in matrix tester but bindings don't show in Vial
    [config.h, keymap.c]
